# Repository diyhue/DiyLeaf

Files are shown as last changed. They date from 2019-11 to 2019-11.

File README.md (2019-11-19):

# DiyLeaf
Triangle lights similar to NanoLeaf

## Requirements

### Control Board  
1 x [ESP-12S/ESP-12E](https://lcsc.com/product-detail/WIFI-Modules_ESP-12S_C82898.html)  
1 x [LM1117F-3.3 SOT-89](https://lcsc.com/product-detail/Low-Dropout-Regulators-LDO_HTC_LM1117F-3-3_LM1117F-3-3_C126019.html)  
2 x Push buttons KEY-6.0*6.0  
8 x [10K 0805 resistors](https://lcsc.com/product-detail/Chip-Resistor-Surface-Mount_Uniroyal-Elec-0805W8J0103T5E_C25612.html)  
2 x [BSS138 transistors](https://lcsc.com/product-detail/MOSFET_Nexperia_BSS138P-215_Nexperia-BSS138P-215_C75547.html)  
1 x [1uF 0805 capacitor](https://lcsc.com/product-detail/Multilayer-Ceramic-Capacitors-MLCC-SMD-SMT_YAGEO-CC0805KKX5R6BB105_C408907.html)  
2 x [47uF 1206 capacitor](https://lcsc.com/product-detail/Multilayer-Ceramic-Capacitors-MLCC-SMD-SMT_SAMSUNG_CL31A476MPHNNNE_47uF-476-20-10V_C96123.html)  
1 x [PCB](https://github.com/diyhue/DiyLeaf/blob/master/PCB's/Gerber_MAIN_BOARD__20191107225850.zip)  

### Panel (1 pcs)  
1  x [ATTINY85-20SU](https://lcsc.com/product-detail/FLASH_ATMEL_ATTINY85-20SU_ATTINY85-20SU_C89852.html)
2  x [100nf 0603 capacitor](https://lcsc.com/product-detail/Multilayer-Ceramic-Capacitors-MLCC-SMD-SMT_YAGEO-AC0603KRX7R9BB104_C149620.html)  
1  x [1uF 0805 capacitor](https://lcsc.com/product-detail/Multilayer-Ceramic-Capacitors-MLCC-SMD-SMT_YAGEO-CC0805KKX5R6BB105_C408907.html)  
18 x [WS2812 3535 leds](https://lcsc.com/product-detail/Light-Emitting-Diodes-LED_3535-RGBIntegrated-Light_C114583.html) Pay attention, regular WS2812 leds come in 5050 package!!  
15 x  [TE Connectivity 1565158-1 contact pad](https://ro.mouser.com/ProductDetail/571-1565158-1)  
1  x [PCB (1mm tick)](https://github.com/diyhue/DiyLeaf/blob/master/PCB's/Gerber_NO-V-CUT-SPRING-3535%20_20191009114030.zip)  
1  x PMMA diffuser  
1 x [back](https://github.com/diyhue/DiyLeaf/blob/master/3D%20Models/Nanoleaf%20-%20back%20cover%20v1.5.stl) and [front](https://github.com/diyhue/DiyLeaf/blob/master/3D%20Models/Nanoleaf%20v1.5.stl) 3D printed parts

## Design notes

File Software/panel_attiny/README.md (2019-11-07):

# Mandatory to flash the binary file from this repo with avrdude and following arguments:

/home/marius/.arduino15/packages/arduino/tools/avrdude/6.3.0-arduino17/bin/avrdude -C/home/marius/.arduino15/packages/ATTinyCore/hardware/avr/1.3.1/avrdude.conf -v -pattiny85 -carduino -P/dev/ttyUSB0 -b19200 -e -Uefuse:w:0xFF:m -Uhfuse:w:0b01010111:m -Ulfuse:w:0xF1:m -Uflash:w:/home/marius/Documents/panel_attiny/panel_attiny/panel_attiny.ino.hex:i

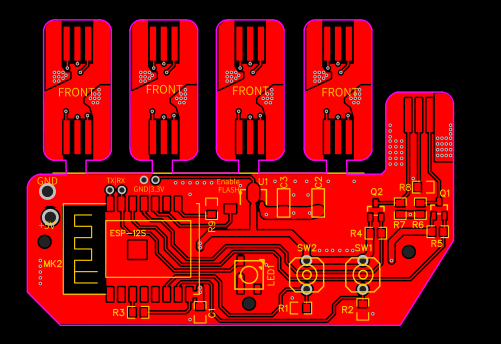
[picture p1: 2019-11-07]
PCB's/Gerber_MAIN_BOARD__20191107225850.png

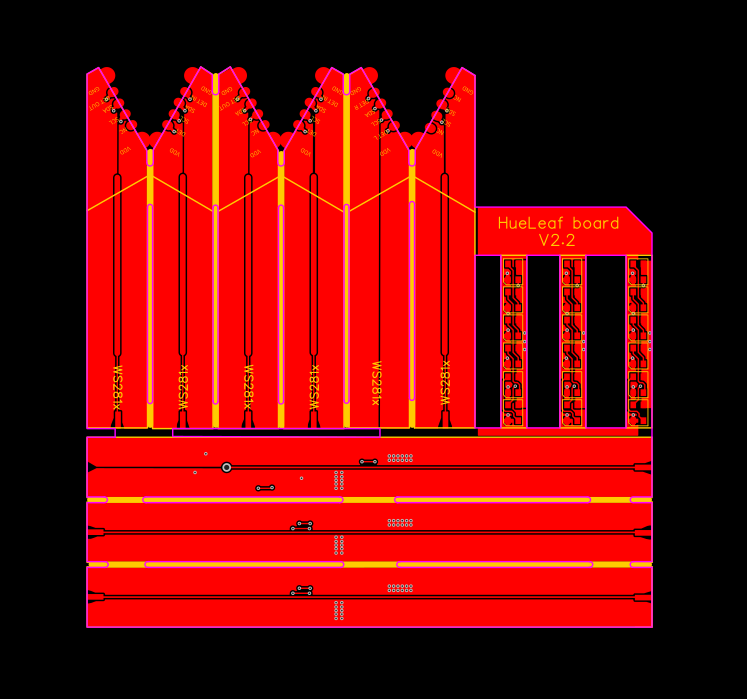
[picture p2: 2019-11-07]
PCB's/Gerber_NO-V-CUT-SPRING-3535 _20191009114030.png

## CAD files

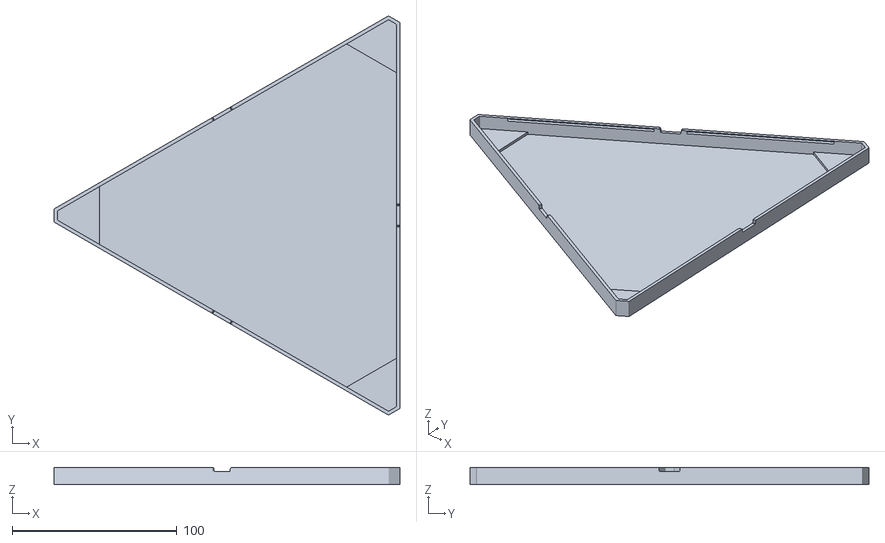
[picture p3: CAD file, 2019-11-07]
3D Models/Nanoleaf v1.5.stl
209.6 x 241.8 x 10.5

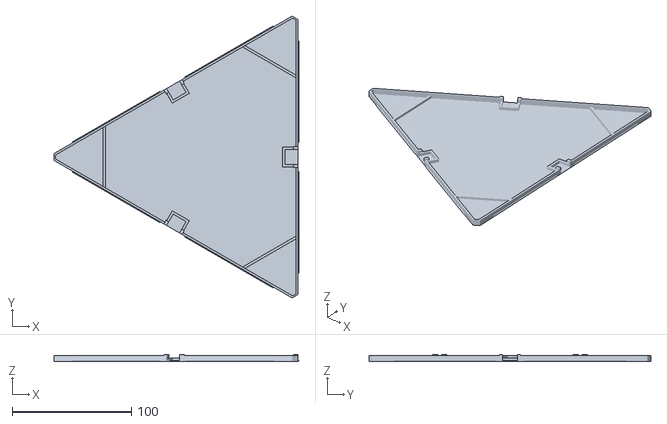
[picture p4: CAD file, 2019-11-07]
3D Models/Nanoleaf - back cover v1.5.stl
205.2 x 235.8 x 6.00

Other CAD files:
3D Models/Nanoleaf - back cover v1.5.CATPart
3D Models/Nanoleaf v1.5.CATPart

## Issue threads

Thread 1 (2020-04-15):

Project Status

BTopbas, 2020-04-15:
This is a working project? Any real photo or video?

mariusmotea, 2020-04-16:
Hi,

This is working but still require improvements on the case side. I don't have a light difusser yet and this is a big minus.

BTopbas, 2020-04-18:
Software is compatible with the original Nanoleaf app? The only minus is a diffuser? And the part list is very specific. We cannot use more accessible items like Arduino pro mini etc? And another thing is PCB. Custom PCB is not easily accessed too. Led parts, maybe we can use ws2815 144led/m led strip 6 led every corner? and some 3d printed case with cable connection paths?

mariusmotea, 2020-04-18:
It is intended to work only with the hue emulator, so you can use hue apps to control these panels (including Hue Sync). I use Attiny85 because is small and cheap. I start with WS2812 which is 5050 format but i notice the case was very thick, so i found the original panels use 3535 leds and ws2812 are available also in this format. You can use arduino, WS281x, but the PCB's and the 3D case from here will not work. Is easy to give it a try if you have one ESP8266 board, one level shifter for i2c bus, arduino boards and WS281x strips

BTopbas, 2020-04-18:
Thanks for the reply! If I will use esp01's every panel and so every panel has different IP and can control separately. is have any minus? (I want to use 9 or more panels.) Or only one IP with data connection between panels And change lights count so split separate panels? Which one is better to do you think?

mariusmotea, 2020-04-26:
If you want to have wifi to every panel and to control it directly from the bridge is very simple, use esp8266 board with generic sw2812 sketch, but this project want to have one master board with esp8266 and controll all other panels using i2c bus.

nasimshah05, 2021-08-13:
i have connect with router but can't connect the esp with emulator.please help

mariusmotea, 2021-08-13:
Open new issue and show logs during light search.

Closed 2020-05-06.

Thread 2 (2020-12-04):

Schematic of the Panel and Control Board

italobbarros, 2020-12-04:
could you send the schematic of the panel to make it easier to understand?

mariusmotea, 2020-12-25:
Sorry, i miss your request. Here is the main board project: https://easyeda.com/marius.motea/nanoleaf-control
And here is the panel project: https://oshwlab.com/marius.motea/NanoLeaf-ATtiny85

Closed 2020-12-25.

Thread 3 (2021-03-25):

Finished product?

jbonnett92, 2021-03-25:
Hi,
I was wondering if you have a video and photos of a finished product?

Thanks,
Jamie

mariusmotea, 2021-06-02:
Almost, but i stop investing time in it. My prototype was working.

Closed 2021-06-18.

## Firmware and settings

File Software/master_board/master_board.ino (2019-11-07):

#include <FS.h>
#include <ESP8266WiFi.h>
#include <ESP8266mDNS.h>
#include <WiFiUdp.h>
#include <ESP8266HTTPUpdateServer.h>
#include <ESP8266WebServer.h>
#include <NeoPixelBus.h>
#include <WiFiManager.h>
#include <ArduinoJson.h>
#include <Wire.h>


#define light_name "NanoLeaf Hue" //default light name
#define maxpanelsCount 20

#define LIGHT_VERSION 3.1
#define LIGHT_NAME_MAX_LENGTH 32 // Longer name will get stripped
#define ENTERTAINMENT_TIMEOUT 1500 // millis

IPAddress address ( 192,  168,   0,  95); // choose an unique IP Adress
IPAddress gateway ( 192,  168,   0,   1); // Router IP
IPAddress submask(255, 255, 255,   0);

NeoPixelBus<NeoGrbFeature, Neo800KbpsMethod> strip(1);

RgbColor red = RgbColor(50, 0, 0);
RgbColor green = RgbColor(0, 50, 0);
RgbColor white = RgbColor(25, 25, 25);
RgbColor yellow = RgbColor(25, 25, 0);
RgbColor magenta = RgbColor(25, 0, 25);
RgbColor black = RgbColor(0);

struct state {
  int ct = 200, hue;
  uint8_t colors[3], bri = 100, sat = 254, colorMode = 2, direction, position_x, position_y;
  float x, y;
  bool lightState, reachable;
};

uint8_t error;
state panels[maxpanelsCount];

unsigned long lastEPMillis;
byte mac[6];
byte packetBuffer[64];

const byte color_red[] = {50, 0, 0, 4};
const byte color_green[] = {0, 50, 0, 4};
const byte color_blue[] = {0, 0, 50, 4};

const byte color_1[] = {200, 100, 0};
const byte color_2[] = {50, 200, 100};
const byte color_3[] = {200, 200, 200};

ESP8266WebServer server(80);
WiFiUDP Udp;
ESP8266HTTPUpdateServer httpUpdateServer;


void blinkLed(uint8_t count, RgbColor color, int interval = 200) {
  strip.SetPixelColor(0, black);
  strip.Show();
  delay(interval);
  for (uint8_t i = 0; i < count; i++) {
    strip.SetPixelColor(0, color);
    strip.Show();
    delay(interval);
    strip.SetPixelColor(0, black);
    strip.Show();
    delay(interval);
  }
  strip.SetPixelColor(0, white);
  strip.Show();
}

void convert_hue(uint8_t panel)
{
  double      hh, p, q, t, ff, s, v;
  long        i;

  s = panels[panel].sat / 255.0;
  v = panels[panel].bri / 255.0;

  if (s <= 0.0) {      // < is bogus, just shuts up warnings
    panels[panel].colors[0] = v;
    panels[panel].colors[1] = v;
    panels[panel].colors[2] = v;
    return;
  }
  hh = panels[panel].hue;
  if (hh >= 65535.0) hh = 0.0;
  hh /= 11850, 0;
  i = (long)hh;
  ff = hh - i;
  p = v * (1.0 - s);
  q = v * (1.0 - (s * ff));
  t = v * (1.0 - (s * (1.0 - ff)));

  switch (i) {
    case 0:
      panels[panel].colors[0] = v * 255.0;
      panels[panel].colors[1] = t * 255.0;
      panels[panel].colors[2] = p * 255.0;
      break;
    case 1:
      panels[panel].colors[0] = q * 255.0;
      panels[panel].colors[1] = v * 255.0;
      panels[panel].colors[2] = p * 255.0;
      break;
    case 2:
      panels[panel].colors[0] = p * 255.0;
      panels[panel].colors[1] = v * 255.0;
      panels[panel].colors[2] = t * 255.0;
      break;

    case 3:
      panels[panel].colors[0] = p * 255.0;
      panels[panel].colors[1] = q * 255.0;
      panels[panel].colors[2] = v * 255.0;
      break;
    case 4:
      panels[panel].colors[0] = t * 255.0;
      panels[panel].colors[1] = p * 255.0;
      panels[panel].colors[2] = v * 255.0;
      break;
    case 5:
    default:
      panels[panel].colors[0] = v * 255.0;
      panels[panel].colors[1] = p * 255.0;
      panels[panel].colors[2] = q * 255.0;
      break;
  }

}

void convert_xy(uint8_t panel)
{
  int optimal_bri = panels[panel].bri;
  if (optimal_bri < 5) {
    optimal_bri = 5;
  }
  float Y = panels[panel].y;
  float X = panels[panel].x;
  float Z = 1.0f - panels[panel].x - panels[panel].y;

  // sRGB D65 conversion
  float r =  X * 3.2406f - Y * 1.5372f - Z * 0.4986f;
  float g = -X * 0.9689f + Y * 1.8758f + Z * 0.0415f;
  float b =  X * 0.0557f - Y * 0.2040f + Z * 1.0570f;


  // Apply gamma correction
  r = r <= 0.04045f ? r / 12.92f : pow((r + 0.055f) / (1.0f + 0.055f), 2.4f);
  g = g <= 0.04045f ? g / 12.92f : pow((g + 0.055f) / (1.0f + 0.055f), 2.4f);
  b = b <= 0.04045f ? b / 12.92f : pow((b + 0.055f) / (1.0f + 0.055f), 2.4f);

  if (r > b && r > g) {
    // red is biggest
    if (r > 1.0f) {
      g = g / r;
      b = b / r;
      r = 1.0f;
    }
  }
  else if (g > b && g > r) {
    // green is biggest
    if (g > 1.0f) {
      r = r / g;
      b = b / g;
      g = 1.0f;
    }
  }
  else if (b > r && b > g) {
    // blue is biggest
    if (b > 1.0f) {
      r = r / b;
      g = g / b;
      b = 1.0f;
    }
  }

  r = r < 0 ? 0 : r;
  g = g < 0 ? 0 : g;
  b = b < 0 ? 0 : b;

  panels[panel].colors[0] = (int) (r * optimal_bri); panels[panel].colors[1] = (int) (g * optimal_bri); panels[panel].colors[2] = (int) (b * optimal_bri);
  //Serial.println("apply XY" + String(panel));
}

void convert_ct(uint8_t panel) {
  int hectemp = 10000 / panels[panel].ct;
  int r, g, b;
  if (hectemp <= 66) {
    r = 255;
    g = 99.4708025861 * log(hectemp) - 161.1195681661;
    b = hectemp <= 19 ? 0 : (138.5177312231 * log(hectemp - 10) - 305.0447927307);
  } else {
    r = 329.698727446 * pow(hectemp - 60, -0.1332047592);
    g = 288.1221695283 * pow(hectemp - 60, -0.0755148492);
    b = 255;
  }
  r = r > 255 ? 255 : r;
  g = g > 255 ? 255 : g;
  b = b > 255 ? 255 : b;
  panels[panel].colors[0] = r * (panels[panel].bri / 255.0f); panels[panel].colors[1] = g * (panels[panel].bri / 255.0f); panels[panel].colors[2] = b * (panels[panel].bri / 255.0f);
  //Serial.println("apply CT " + String(panel));
}

void handleNotFound() {
  String message = "File Not Found\n\n";
  message += "URI: ";
  message += server.uri();
  message += "\nMethod: ";
  message += (server.method() == HTTP_GET) ? "GET" : "POST";
  message += "\nArguments: ";
  message += server.args();
  message += "\n";
  for (uint8_t i = 0; i < server.args(); i++) {
    message += " " + server.argName(i) + ": " + server.arg(i) + "\n";
  }
  server.send(404, "text/plain", message);
}


void processLightdata(uint8_t panel) {
  if (panels[panel].colorMode == 1 && panels[panel].lightState == true) {
    convert_xy(panel);
  } else if (panels[panel].colorMode == 2 && panels[panel].lightState == true) {
    convert_ct(panel);
  } else if (panels[panel].colorMode == 3 && panels[panel].lightState == true) {
    convert_hue(panel);
  } else {
    panels[panel].colors[0] = 0; panels[panel].colors[1] = 0; panels[panel].colors[2] = 0;
  }
}

void assignAddress() {
  for (uint8_t address = 10; address < maxpanelsCount + 10; address++ )  {
    Wire.beginTransmission(address);
    error = Wire.endTransmission();
    if (error != 0) {
      Wire.beginTransmission(0x7E);
      Wire.write(address);
      Wire.endTransmission();
      return;
    }
  }
}

bool check_pannel_online (uint8_t panelId) {
  Wire.beginTransmission(panelId + 10);
  error = Wire.endTransmission();
  if (error == 0) {
    panels[panelId].reachable = true;
    return true;
  } else {
    panels[panelId].reachable = false;
    return false;
  }
}

bool check_temporary_address() {
  Wire.beginTransmission(0x7E);
  error = Wire.endTransmission();
  if (error == 0) {
    assignAddress();
    blinkLed (1, green, 500);
    return true;
  } else {
    blinkLed (1, red, 500);
    return false;
  }
}


void detection() {
  check_temporary_address();
  for (uint8_t panel = 0; panel < maxpanelsCount; panel++) {
    check_pannel_online(panel);
    if (panels[panel].reachable == true) {
      blinkLed (1, magenta, 500);
      byte i2cMessage[2] = {252, 250};
      Wire.beginTransmission(panel + 10);
      Wire.write(i2cMessage, 2);
      Wire.endTransmission();
      delay(200);
      check_temporary_address();
      i2cMessage[1] = 251;
      Wire.beginTransmission(panel + 10);
      Wire.write(i2cMessage, 2);
      Wire.endTransmission();
      delay(200);
      check_temporary_address();
    }
  }
}

void setup()  {
  pinMode(12, INPUT);
  pinMode(13, INPUT);
  strip.Begin();
  //strip.Show();
  //Serial.begin(115200);
  delay(100);
  strip.SetPixelColor(0, red);
  strip.Show();
  Wire.begin(5, 4);
  delay(100);

  for (uint8_t address = 0; address <  120; address++ )  {
    Wire.beginTransmission(address);
    error = Wire.endTransmission();
    if (error == 0) {
      //Serial.print((String)address + ", ");
    }
  }

#ifdef USE_STATIC_IP
  WiFi.config(strip_ip, gateway_ip, subnet_mask);
#endif

  WiFiManager wifiManager;
  wifiManager.setConfigPortalTimeout(120);
  wifiManager.autoConnect(light_name);

  WiFi.macAddress(mac);

  blinkLed(2, green);

  httpUpdateServer.setup(&server);

  Udp.begin(2100);

  server.on("/config", HTTP_POST, []() {


    server.send ( 200, "text/json", server.arg("plain") );
  });

    server.on("/state", HTTP_PUT, []() {
    bool stateSave = false;
    DynamicJsonDocument root(1024);
    DeserializationError error = deserializeJson(root, server.arg("plain"));

    if (error) {
      server.send(404, "text/plain", "FAIL. " + server.arg("plain"));
    } else {
      for (JsonPair state : root.as<JsonObject>()) {
        const char* key = state.key().c_str();
        int light = atoi(key) - 1;
        JsonObject values = state.value();
        int transitiontime = 4;

        if (values.containsKey("xy")) {
          panels[light].x = values["xy"][0];
          panels[light].y = values["xy"][1];
          panels[light].colorMode = 1;
        } else if (values.containsKey("ct")) {
          panels[light].ct = values["ct"];
          panels[light].colorMode = 2;
        } else {
          if (values.containsKey("hue")) {
            panels[light].hue = values["hue"];
            panels[light].colorMode = 3;
          }
          if (values.containsKey("sat")) {
            panels[light].sat = values["sat"];
            panels[light].colorMode = 3;
          }
        }

        if (values.containsKey("on")) {
          if (values["on"]) {
            panels[light].lightState = true;
          } else {
            panels[light].lightState = false;
          }
        }

        if (values.containsKey("bri")) {
          panels[light].bri = values["bri"];
        }

        if (values.containsKey("bri_inc")) {
          panels[light].bri += (int) values["bri_inc"];
          if (panels[light].bri > 255) panels[light].bri = 255;
          else if (panels[light].bri < 1) panels[light].bri = 1;
        }

        if (values.containsKey("transitiontime")) {
          transitiontime = values["transitiontime"];
        }

        processLightdata(light);
        byte payload[4];
        payload[0] = char(panels[light].colors[0]); payload[1] = char(panels[light].colors[1]); payload[2] = char(panels[light].colors[2]); payload[3] = transitiontime;
        Wire.beginTransmission(light + 10);
        Wire.write(payload, 4);
        Wire.endTransmission();
      }
      
      String output;
      serializeJson(root, output);
      server.send(200, "text/plain", output);
    }
  });

  server.on("/i2c", []() {
    String output;
    for (uint8_t address = 0; address <  127; address++ )  {
      Wire.beginTransmission(address);
      error = Wire.endTransmission();
      if (error == 0) {
        output += (String)address + ", ";
      }
    }
    server.send(200, "text/plain", "i2c scan result " + output);
  });


  server.on("/state", HTTP_GET, []() {

    uint8_t light;
    if (server.hasArg("light"))
      light = server.arg("light").toInt() - 1;

    DynamicJsonDocument root(1024);
    root["lightState"] = panels[light].lightState;
    root["bri"] = panels[light].bri;
    JsonArray xy = root.createNestedArray("xy");
    xy.add(panels[light].x);
    xy.add(panels[light].y);
    root["ct"] = panels[light].ct;
    root["hue"] = panels[light].hue;
    root["sat"] = panels[light].sat;
    if (panels[light].colorMode == 1)
      root["colormode"] = "xy";
    else if (panels[light].colorMode == 2)
      root["colormode"] = "ct";
    else if (panels[light].colorMode == 3)
      root["colormode"] = "hs";
    String output;
    serializeJson(root, output);
    server.send(200, "text/plain", output);
  });

  server.on("/detect", []() {
    uint8_t detectedLights = 0;
    for (uint8_t address = 10; address < maxpanelsCount + 10; address++ )  {
      Wire.beginTransmission(address);
      error = Wire.endTransmission();
      if (error == 0) {
        detectedLights++;
      }
    }
    char macString[32] = {0};
    sprintf(macString, "%02X:%02X:%02X:%02X:%02X:%02X", mac[0], mac[1], mac[2], mac[3], mac[4], mac[5]);
    DynamicJsonDocument root(1024);
    root["name"] = light_name;
    root["hue"] = "bulb";
    root["protocol"] = "native_multi";
    root["lights"] = detectedLights;
    root["modelid"] = "LCT015";
    root["type"] = "json";
    root["mac"] = String(macString);
    root["version"] = 2.0;
    String output;
    serializeJson(root, output);
    server.send(200, "text/plain", output);
  });

  server.on("/reset", []() {
    server.send(200, "text/plain", "perform reset");
    delay(100);
    blinkLed(2, yellow);
    ESP.reset();
  });

  server.on("/scan", []() {
    server.send(200, "text/plain", "scanning...");
    blinkLed(1, yellow);
    detection();
  });

  server.onNotFound(handleNotFound);

  server.begin();
}

void entertainment() {
  uint8_t packetSize = Udp.parsePacket();
  if (packetSize) {
    Udp.read(packetBuffer, packetSize);
    for (uint8_t i = 0; i < packetSize / 4; i++) {
      panels[packetBuffer[i * 4]].colors[0] = packetBuffer[i * 4 + 1];
      panels[packetBuffer[i * 4]].colors[1] = packetBuffer[i * 4 + 2];
      panels[packetBuffer[i * 4]].colors[2] = packetBuffer[i * 4 + 3];
      byte rgb[3] = {panels[packetBuffer[i * 4]].colors[0], panels[packetBuffer[i * 4]].colors[1], panels[packetBuffer[i * 4]].colors[2]};
      Wire.beginTransmission((packetBuffer[i * 4] + 10));
      Wire.write(rgb, 3);
      Wire.endTransmission();
      delay(2);
    }
  }
}


void loop()
{
  //lightEngine();
  server.handleClient();
  entertainment();
  if (digitalRead(12) == HIGH) {
    blinkLed(2, yellow);
    delay(100);
    ESP.reset();
  }
  if (digitalRead(13) == HIGH) {
    blinkLed(1, yellow);
    detection();
  }
}

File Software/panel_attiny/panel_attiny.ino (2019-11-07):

#include <EEPROM.h>
#include <Wire.h>
#include <Adafruit_NeoPixel.h>


uint8_t colors[3], i2cBuffer[10], left, right;
float step_level[3], current_colors[3];
bool inTransition, configured;


void(* resetFunc) (void) = 0;

Adafruit_NeoPixel pixels = Adafruit_NeoPixel(18, 1, NEO_GRB + NEO_KHZ800);


void setPanelColor(int8_t r, int8_t g, int8_t b) {
  for (int8_t i = 0; i < 18; i++) {
    pixels.setPixelColor(i, pixels.Color(r, g, b));
  }
  pixels.show();
}

void lightEngine() {
  for (uint8_t color = 0; color < 3; color++) {
    if (colors[color] != current_colors[color] ) {
      inTransition = true;
      current_colors[color] += step_level[color];
      if ((step_level[color] > 0.0f && current_colors[color] > colors[color]) || (step_level[color] < 0.0f && current_colors[color] < colors[color])) current_colors[color] = colors[color];
    }
  }
  if (inTransition) {
    setPanelColor(current_colors[0], current_colors[1], current_colors[2]);
    inTransition = false;
  }
}


void applyColor(uint8_t r, uint8_t g, uint8_t b) {
  colors[0] = r; colors[1] = g; colors[2] = b;
}

void process_lightdata(int transitiontime) {
  for (uint8_t color = 0; color < 3; color++) {
    step_level[color] = (float (colors[color]) - current_colors[color]) / float (transitiontime * 1);
  }
}

void notifyLeft() {
  pinMode(left, OUTPUT);
  digitalWrite(left, LOW);
  delay(100);
  pinMode(left, INPUT_PULLUP);
}

void notifyRight() {
  pinMode(right, OUTPUT);
  digitalWrite(right, LOW);
  delay(100);
  pinMode(right, INPUT_PULLUP);
}

void applyColorToAll(int8_t r, int8_t g, int8_t b, int transitiontime = 4) {
  for (int8_t edge = 0; edge < 3; edge++) {
    colors[0] = r;
    colors[1] = g;
    colors[2] = b;
    process_lightdata(transitiontime);
  }
}

void setNewAddress(uint8_t howMany)
{
  EEPROM.write(0x00, 1);
  EEPROM.write(0x01, Wire.read());
  delay(50);
  resetFunc();
}


void receiveEvent(uint8_t howMany)
{
  uint8_t packet = 0;
  while (Wire.available() > 0) {
    i2cBuffer[packet] = Wire.read();
    packet++;
    //Serial.println("packets set " + (String)packet);
  }
  if (howMany == 2)
  {
    //Serial.println("received 2 bytes");
    if (i2cBuffer[0] == 252) {
      if (i2cBuffer[1] == 250) {
        applyColor(0, 25, 25);
        process_lightdata(4);
        notifyLeft();
      } else if (i2cBuffer[1] == 251) {
        applyColor(25, 20, 30);
        process_lightdata(4);
        notifyRight();
      } else if (i2cBuffer[1] == 252) {
        delay(50);
        resetFunc();
      } else {
        //Serial.println("change i2c address to " + (String)i2cBuffer[1]);
        applyColorToAll(25, 0, 25);
        Wire.begin(i2cBuffer[1]);
        Wire.onReceive(receiveEvent);
      }
    }
  }

  else if (howMany == 3) {
    //Serial.println("received 3 bytes");
    setPanelColor(i2cBuffer[0], i2cBuffer[1], i2cBuffer[2]);
  }

  else if (howMany == 4) {
    //Serial.println("received 4 bytes");
    applyColor(i2cBuffer[0],i2cBuffer[1],i2cBuffer[2]);
    process_lightdata(4);
    //setPanelColor(i2cBuffer[0], i2cBuffer[1], i2cBuffer[2]);
  }
}

void setup()
{
  //Serial.begin(9600);
  //Serial.println("starting...");
  pinMode(3, INPUT_PULLUP);
  pinMode(4, INPUT_PULLUP);
  pinMode(5, INPUT_PULLUP);

  pixels.begin();

  if (EEPROM.read(0x00) == 1) {
    Wire.begin(EEPROM.read(0x01));
    Wire.onReceive(receiveEvent);
    EEPROM.write(0x00, 0);
    applyColor(0, 50, 0);
    if (EEPROM.read(0x02) == 3) {
      left = 4; right = 5;
    } else if (EEPROM.read(0x02) == 4) {
      left = 5; right = 3;
    } else {
      left = 3; right = 4;
    }
    configured = true;
  } else {
    applyColor(50, 0, 0);
  }
  process_lightdata(4);
}

void loop()
{
  lightEngine();
  if (!configured) {
    while (digitalRead(3) == HIGH && digitalRead(4) == HIGH && digitalRead(5) == HIGH) {
      lightEngine();
    }

    if (digitalRead(3) == LOW) {
      EEPROM.write(0x02, 3);
    } else if (digitalRead(4) == LOW) {
      EEPROM.write(0x02, 4);
    } else if (digitalRead(5) == LOW) {
      EEPROM.write(0x02, 5);
    }

    Wire.begin(0x7E);
    Wire.onReceive(setNewAddress);

    applyColor(25, 25, 0);
    process_lightdata(4);
    configured = true;
  }
  delay(50);
}
